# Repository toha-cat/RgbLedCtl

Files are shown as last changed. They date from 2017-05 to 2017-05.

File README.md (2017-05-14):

# RgbLedCtl
RgbLedCtl is an electronic unit and application for controlling RGB led. Communication with the electronic unit is carried out via WiFi.
Based on ESP8266 WiFi SOC with NodeMCU firmware.

The project consists of an electrical unit, lua scripts for ESP8266 and RGBLed -
 control applications.

# Principle of operation
After switching on, the unit is connected to the specified WiFi point. The client (RGBLed) connects to it on the tcp socket. The client sends commands - a color in the form of HEX RGB. The MCU generates the corresponding PWM signals to the keys.

# Electrical scheme
Electrical scheme - project for KiCad. Input power supply 12V. With the help of DC-DK 12v is converted into 5v. whis a linear regulator LM1113 converted 5v to 3.3v. 5v are needed to connect an additional control panel (will be added in the next versions). MOSFETs are used as keys.

# ESP8266 firmware
NodeMCU is used as the firmware. The site of the project http://nodemcu.com/index_en.html. Instructions for the flash firmware https://nodemcu.readthedocs.io/en/master/en/flash/.
After the flash, you need to load lua scripts (from the folder McuScripts) in the MCU. For load scripts recommend using the utility ESPlorer - https://github.com/4refr0nt/ESPlorer.
Before load scripts, rename config.lua.example to config.lua and enter the parameters of your WiFi into it.

# RGBLed
RGBLed - application for control backlight. This is a cross-platform application written using Qt5. The interface is written in QML. The application source code is located in the RGBLed directory as a project for QtCreator.
Qt libraries and theirs source code, as well as QtCreator, can be found on the official Qt website - https://www.qt.io/
Link to the download page Qt5 https://www.qt.io/download-open-source/

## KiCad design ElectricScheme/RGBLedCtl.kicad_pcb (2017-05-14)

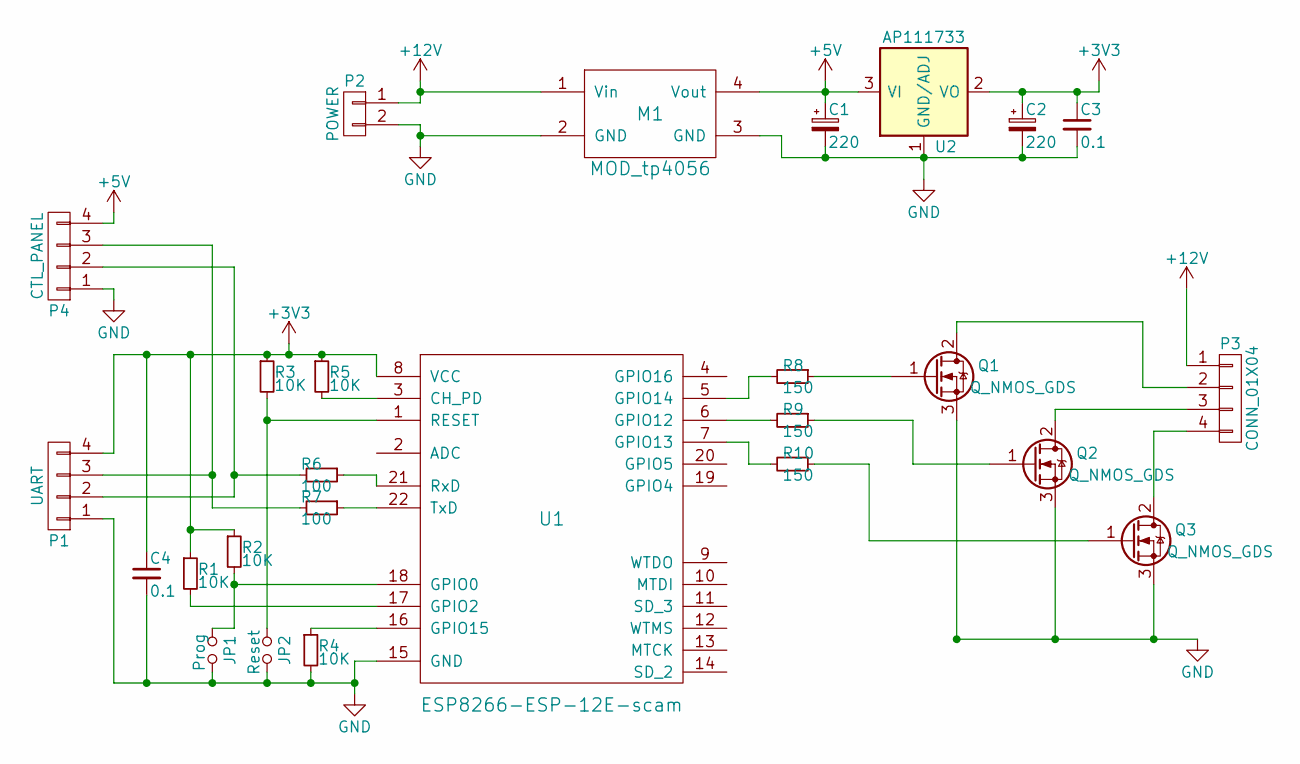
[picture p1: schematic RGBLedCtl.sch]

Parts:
C1, C2: 220; C_Radial_D6.3_L11.2_P2.5
C3, C4: 0.1; C_0805_HandSoldering
JP1: Prog; Pin_Header_Straight_1x02
JP2: Reset; SW_PUSH_6mm
M1: MOD_tp4056; DC-DC-mini
P1: UART; Pin_Header_Straight_1x04
P2: POWER; TerminalBlock_Pheonix_PT-3.5mm_2pol
P3: CONN_01X04; TerminalBlock_Pheonix_PT-3.5mm_4pol
P4: CTL_PANEL; Socket_Strip_Straight_1x04
Q1, Q2, Q3: Q_NMOS_GDS; TO-252-2Lead
R1, R2, R3, R4, R5: 10K; R_0805_HandSoldering
R6, R7: 100; R_0805_HandSoldering
R8, R9, R10: 150; R_0805_HandSoldering
U1: ESP8266-ESP-12E-scam; ESP-12E
U2: AP111733; SOT-223

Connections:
+3V3: C2.1, C3.1, C4.1, P1.4, R1.1, R2.1, R3.1, R5.1, U1.8 (VCC), U2.2 (VO), U2.4 (VO)
+5V: C1.1, M1.4 (Vout), P4.4, U2.3 (VI)
+12V: M1.1 (Vin), P2.1, P3.1
GND: C1.2, C2.2, C3.2, C4.2, JP1.2, JP2.2, M1.2 (GND), M1.3 (GND), P1.1, P2.2, P4.1, Q1.3 (S), Q2.3 (S), Q3.3 (S), R4.2, U1.15 (GND), U2.1 (GND/ADJ)
unnamed: JP1.1, R2.2, U1.18 (GPIO0)
unnamed: JP2.1, R3.2, U1.1 (RESET)
unnamed: P1.2, P4.2, R6.2
unnamed: P1.3, P4.3, R7.2
unnamed: P3.2, Q1.2 (D)
unnamed: P3.3, Q2.2 (D)
unnamed: P3.4, Q3.2 (D)
unnamed: Q1.1 (G), R8.1
unnamed: Q2.1 (G), R9.1
unnamed: Q3.1 (G), R10.1
unnamed: R1.2, U1.17 (GPIO2)
unnamed: R4.1, U1.16 (GPIO15)
unnamed: R5.2, U1.3 (CH_PD)
unnamed: R6.1, U1.21 (RxD)
unnamed: R7.1, U1.22 (TxD)
unnamed: R8.2, U1.5 (GPIO14)
unnamed: R9.2, U1.6 (GPIO12)
unnamed: R10.2, U1.7 (GPIO13)

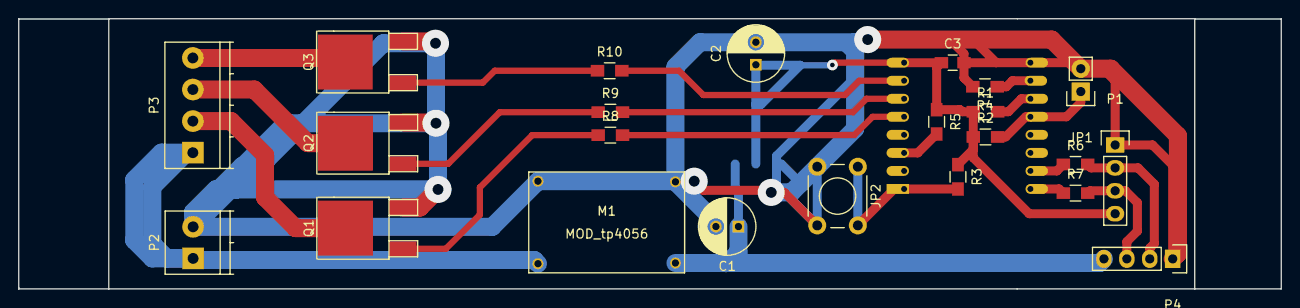
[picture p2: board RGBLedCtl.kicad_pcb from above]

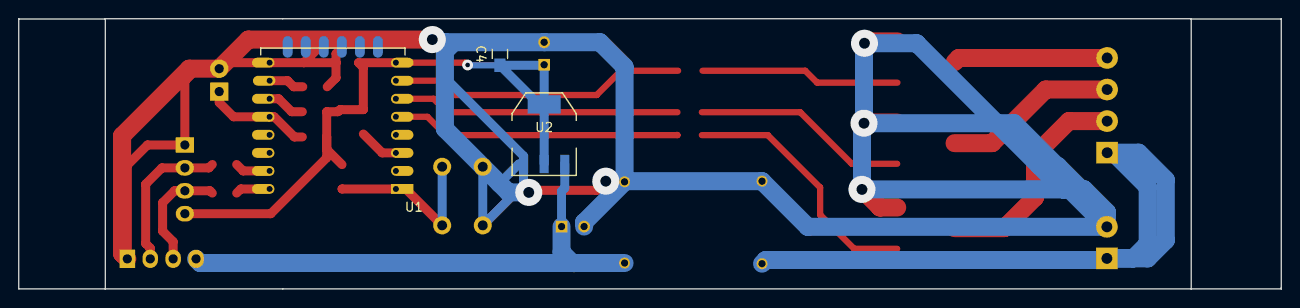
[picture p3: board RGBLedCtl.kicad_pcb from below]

Board: 2 copper layers, 140.0 x 30.0 mm, 26 parts (3 on the bottom side), 22 nets.

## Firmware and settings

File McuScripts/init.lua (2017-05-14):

dofile("config.lua")

redV = 0
blueV = 0
greenV = 0

server = 0

clientList = {}

-- normalize value from PWM
function normalize(v)
	return v*4
--	return v*(v/128)
end
-- PWM initialization for LED and setting of start values
function initLed()
	pwm.setup(5,200,256) 
	pwm.setup(6,200,256) 
	pwm.setup(7,200,256)

	pwm.setduty(5,0) 
	pwm.setduty(7,0) 
	pwm.setduty(6,0)

	pwm.start(5) 
	pwm.start(6) 
	pwm.start(7)
end
-- Set the color of LED
function setLedColor(r,g,b) 
	pwm.setduty(5,normalize(r)) 
	pwm.setduty(7,normalize(g)) 
	pwm.setduty(6,normalize(b))
end
-- Get the current LED color in RGB
function getColor()
	return string.format("#%02x/%02x/%02x", redV, blueV, greenV)
end
-- Get the value of each color from RGB
function parseColor(color)
	print(color)
	redV = tonumber(color:sub(2,3), 16)
	greenV = tonumber(color:sub(4,5), 16)
	blueV = tonumber(color:sub(6,7), 16)
	return redV, greenV, blueV
end
-- Set the color of the LED, input parameter RGB string
function setColor(color)
	parseColor(color)
	setLedColor(redV, greenV, blueV)
end
--  Initializing WiFi as a client and connecting to the network
function initNetwork()
	cfg = {}
	cfg.ip=c_ip
	cfg.netmask=c_netmask
	cfg.gateway=c_gateway
	wifi.sta.setip(cfg)
	wifi.setmode(wifi.STATION)
	wifi.sta.config(c_wifi_ssid,c_wifi_key,1)  -- enable auto connect and connect to access point
end
-- Parsing messages from clients
function readyMess(client, mess)
	-- TODO processing of commands, not only color can come, but also animation
	setColor(mess)
end
-- Sending messages to clients
function sendMess(mess)
	for i = 1, #clientList, 1 do
		local c = clientList[i]
		c:send(mess)
	end
end
-- Removing clients from the list
function removeClient(client)
	local cIp,cPort = client:getpeer()
	for i = 1, #clientList, 1 do
		local c = clientList[i]
		local ip,port = c:getpeer()
		if ip == cIp and cPort == port then
			table.remove(clientList, i)
			break
		end
	end
end
-- Create and start a TCP server
function initServer( ... )
	server = net.createServer(net.TCP, 3000)
	server:listen(5050,
		function(c)
			c:on("receive", readyMess)
			c:on("disconnection", removeClient)
			table.insert(clientList, c)
			-- c:send("hello world")
		end
	)
end

initLed()
initNetwork()
initServer()
